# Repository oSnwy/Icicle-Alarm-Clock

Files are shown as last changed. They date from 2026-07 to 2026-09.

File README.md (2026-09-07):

# Icicle-Alarm-Clock

## Finished Build Images

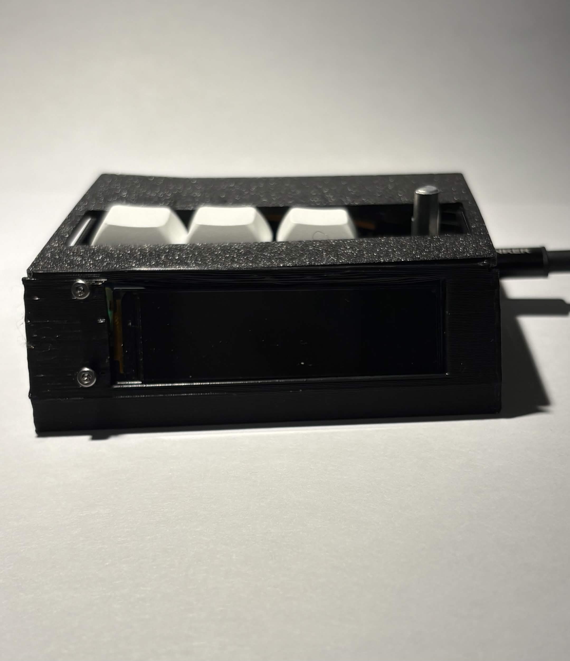
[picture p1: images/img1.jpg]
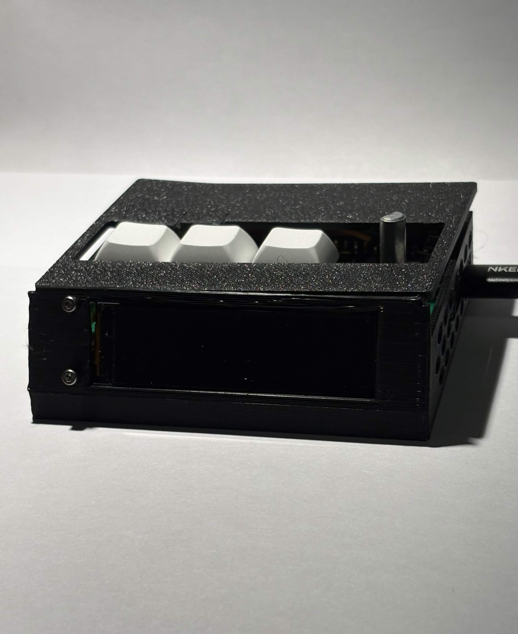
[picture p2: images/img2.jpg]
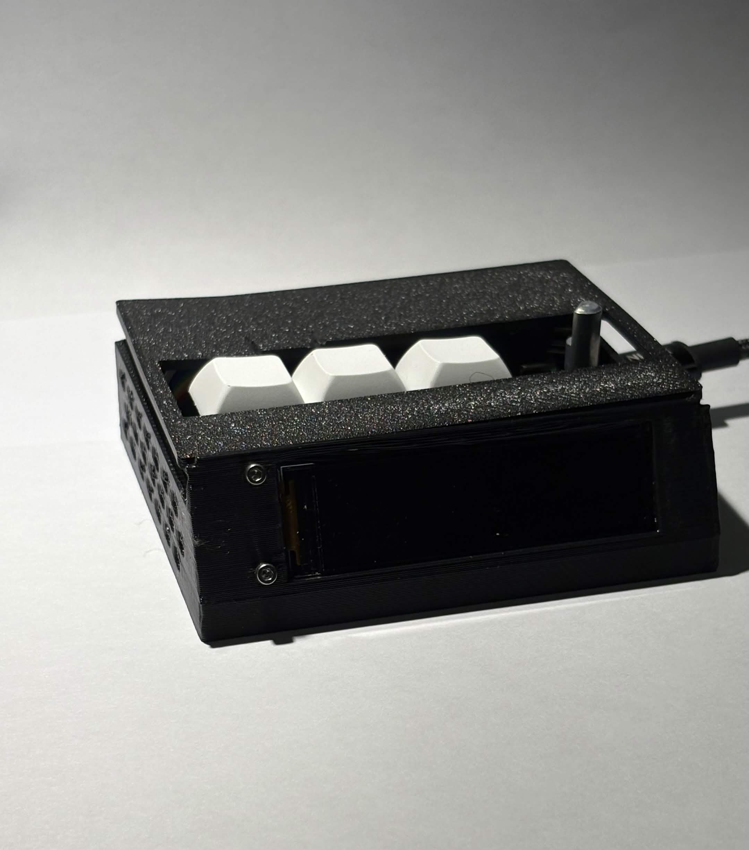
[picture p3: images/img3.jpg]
| </p> | </p> |  </p> |
| - | - | - |

<p align="center">
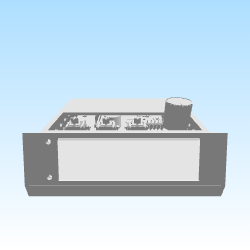
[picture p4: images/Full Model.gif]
  </p>
</p>

## Initial goals:
### Priority Goals:
- This alarm clock should be able to tell the time (obviously).
- This alarm clock should be able to store multiple alarms, as well as be able to toggle each alarm.
### Less important goals
- This alarm clock should have a volume knob.
- This alarm clock should be able to play customized sounds.

## Parts list (Bill of Materials)

| Part | Quantity | Price | Link |  
| --- | --- | --- | --- |
| Lolin C3 Mini ESP32 | 1 | Provided in Kit | N/A |
| 2.25in TFT display | 1 | Provided in Kit | N/A |
| Custom PCB | 1 | $8.67 | JLPCB |
| 3.3V Piezo Buzzer | 1 | Provided in Kit | N/A |
| EC11 Rotary Encoder Switch Button | 1 | $7.55 CAD | [AliExpress](https://www.aliexpress.com/item/1005008610645902.html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) |
| 1k ohm Resistor | 1 | $0.88 CAD | [AliExpress](https://www.aliexpress.com/item/1005007643210127.html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) |
| 10k Ohm Resistor | 1 | $0.88 CAD | [AliExpress](https://www.aliexpress.com/item/1005007643210127.html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) |
| S8050 Transistor | 1 | $7.47 CAD | [AliExpress](https://www.aliexpress.com/item/1005006811049225.html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) |
| Case | 1 | Provided in Kit | N/A |
| Lid | 1 | Provided in Kit | N/A |
| 1x8 2.54mm pin headers | 2 | $3.72 CAD | [AliExpress](https://www.aliexpress.com/item/32847429443.html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) |
| Keyboard Switches | 3 | Provided in Kit | N/A |
| Keyboard Keycaps | 3 | Provided in Kit | N/A |
| Male to male Dupont wires | 16 | $3.50 CAD | [AliExpress](https://www.aliexpress.com/item/4000109443054.html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) | 

| Price | HST (Ontario Sales Tax) | Total Price | Total USD Price |  
| --- | --- | --- | --- |
| $32.67 CAD |  $4.25 CAD HST) | $36.92 CAD | 26.01 USD |

## Planning:
- I plan to use a rotary encoder with a switch to navigate the UI, as well as extra switches to toggle alarms or other features easily.
- The buzzer will be integrated into a transistor circuit, increasing the volume of the alarm while keeping it adjustable.

## Schemtaic (4 Hours):
- Due to the struggle for GPIO pins on the WEMOS, I was only able to add two switches.
- The rotary encoder and two switches use 5 GPIO pins, while the buzzer uses one.
- The THT display uses the other 6 GPIO pins.
- The 3.3V pin powers both the buzzer and the THT display.
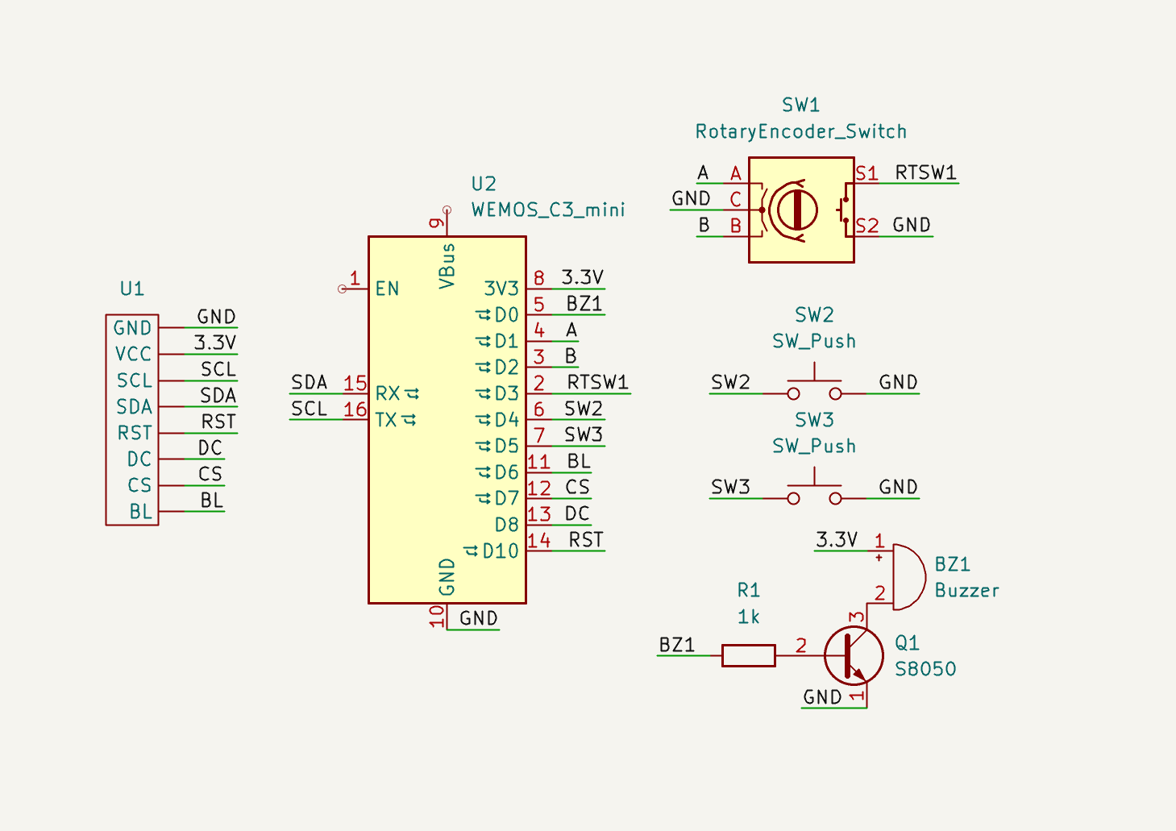
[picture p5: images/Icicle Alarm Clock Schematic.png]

  
## Schematic (REVISED: +2 Hours):
- While creating the PCB, I added a pull-down resistor between the base of the transistor circuit and the GND pin.
- I changed the THT display to be connected with a generic 2.54mm 1x8 connector, so the keys and screen can be mounted on separate planes.
- The BL is now powered by the 3.3V pin, freeing the GPIO pin to be used for a third switch.
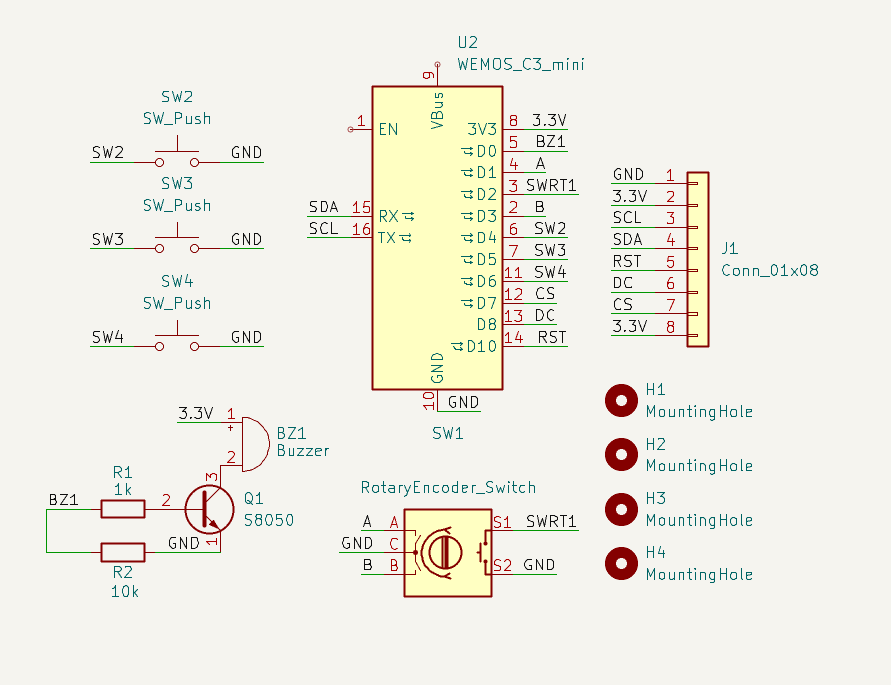
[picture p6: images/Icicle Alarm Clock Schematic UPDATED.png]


## PCB (4 Hours)
- The PCB was wired in KiCad, using the footprints provided by Hack Club [BLARE](https://github.com/destroyer796/BLARE-Alarm-Clock/tree/main).
- All components were mounted on the top of the PCB.
- The PCB includes 4 mounting holes for M3 screws.
- This PCB uses a 1x8 connector for the display.
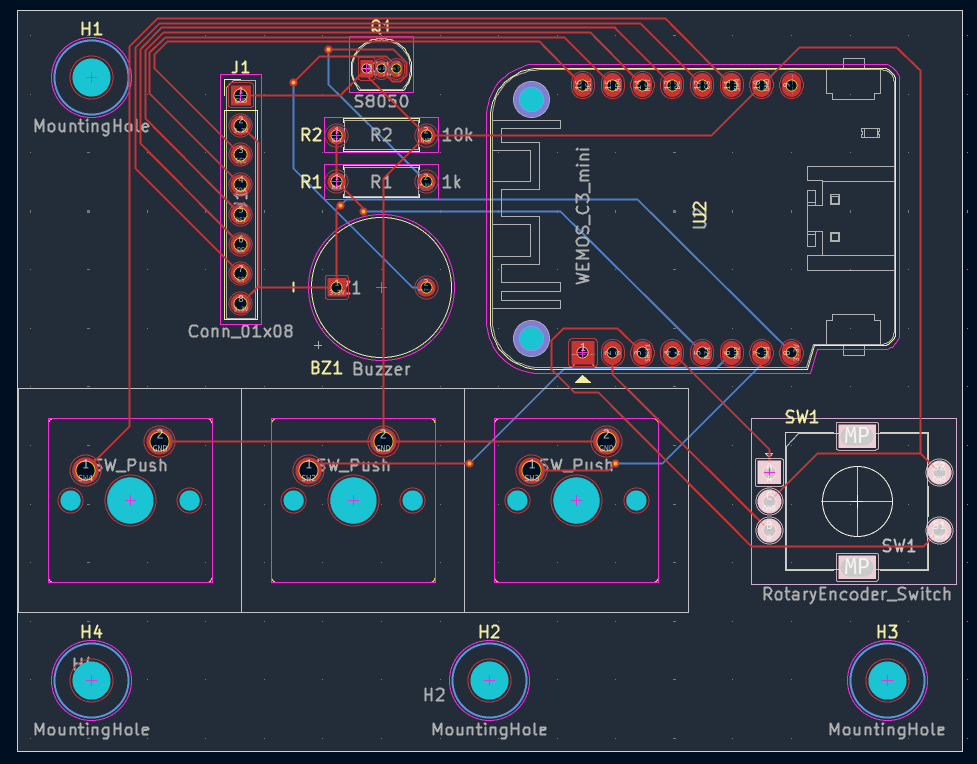
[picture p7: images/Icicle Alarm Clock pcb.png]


## Case (3 Hours)
This case is designed to work in two parts. The main body of the case has M3 screw standoffs in the base, allowing the PCB to be screwed into the case securely. The LCD can be attached to the front of the case using M2 screws in the hole in the front. The lid functions as a quick access to all the componenets inside, as well as contains a hole to reach the knob and switches. The side of the case contains cutouts to better transmit the sound of the buzzer.
- All 3d files can be found in the 3d model folder.
- The case and lid are stored in [/3d models/STEP files/Alarm Clock Base.step](https://github.com/oSnwy/Icicle-Alarm-Clock/blob/main/3d%20models/STEP%20files/Alarm%20Clock%20Base.step) and [/3d models/STEP files/Alarm Clock Lid.step](https://github.com/oSnwy/Icicle-Alarm-Clock/blob/main/3d%20models/STEP%20files/Alarm%20Clock%20Lid.step)

## CASE (REVISED: +2 Hours):
Added holes for the usb c wire, as well as a lower lid for easier access to the switches. Also added full electronics 3d model.

### Full Model With Electronics

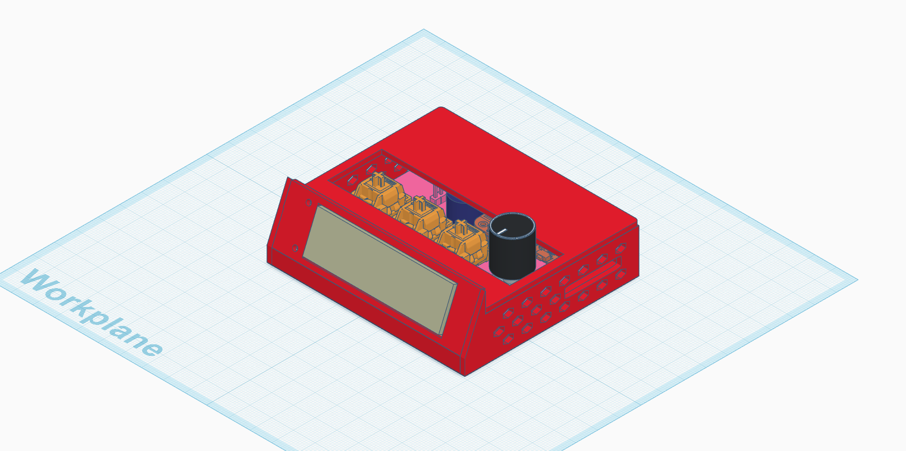
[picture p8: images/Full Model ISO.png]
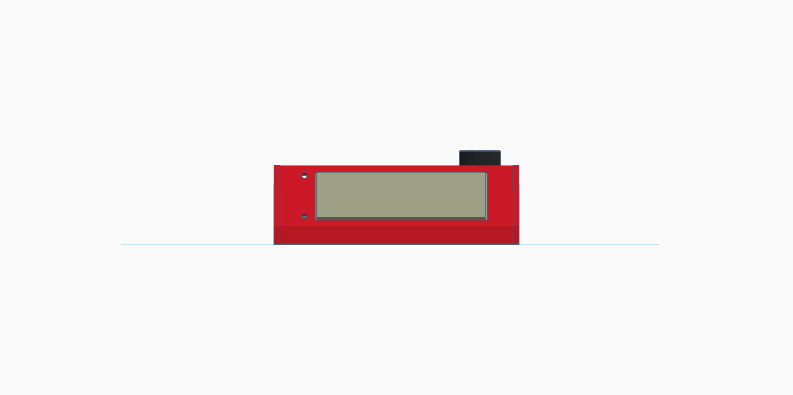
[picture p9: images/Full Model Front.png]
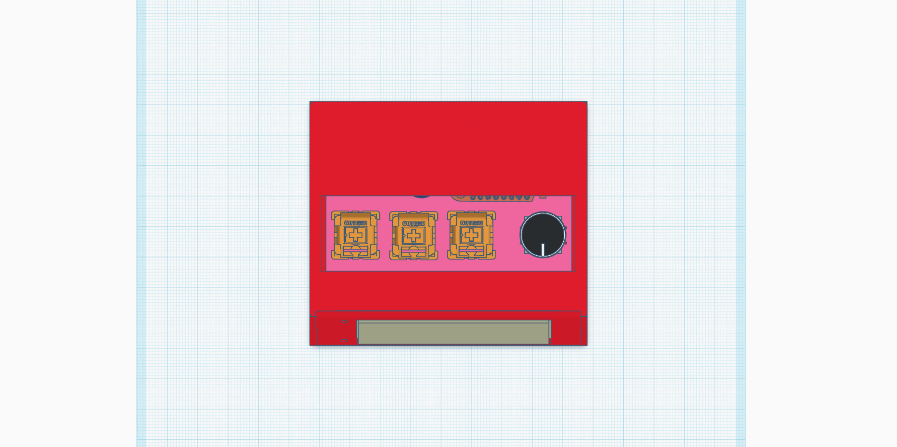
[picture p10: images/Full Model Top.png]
|  |  |  |
|-|-|-|
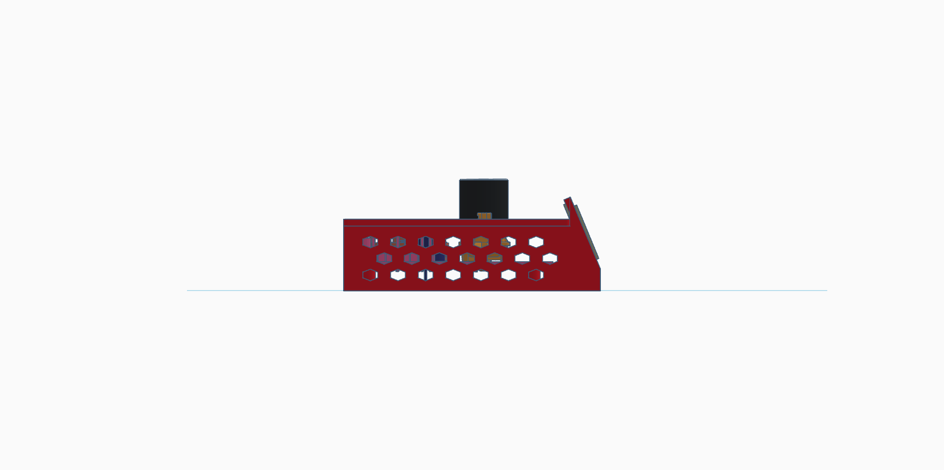
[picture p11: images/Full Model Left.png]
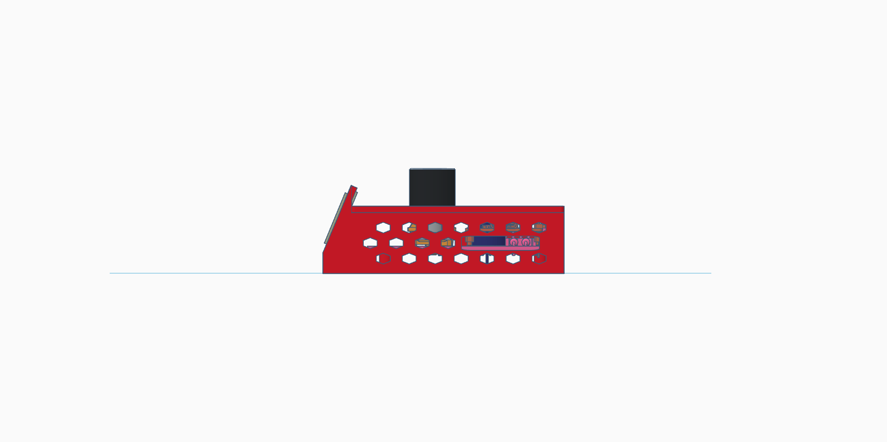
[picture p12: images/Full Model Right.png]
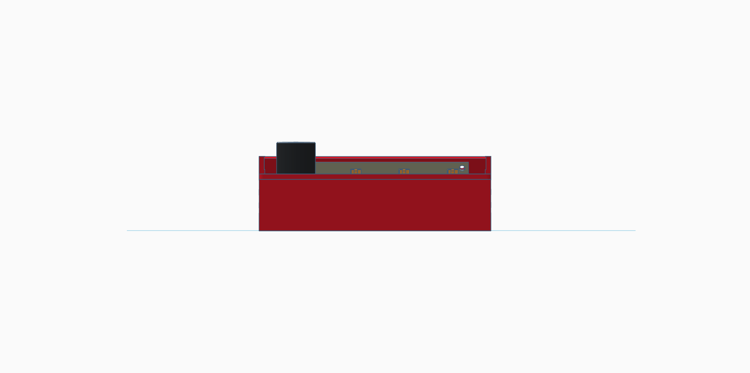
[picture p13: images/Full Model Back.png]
|  |  |  |

### Case

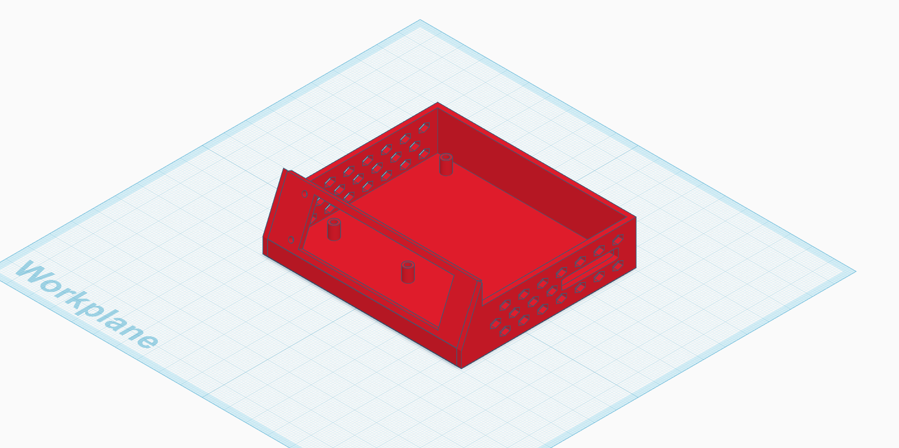
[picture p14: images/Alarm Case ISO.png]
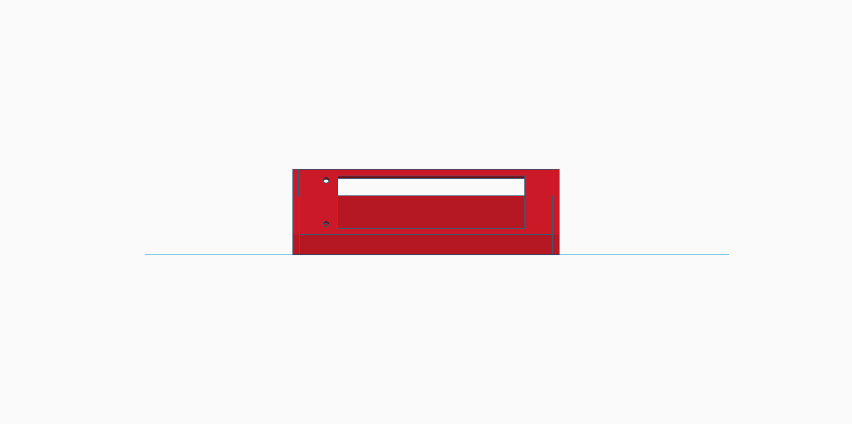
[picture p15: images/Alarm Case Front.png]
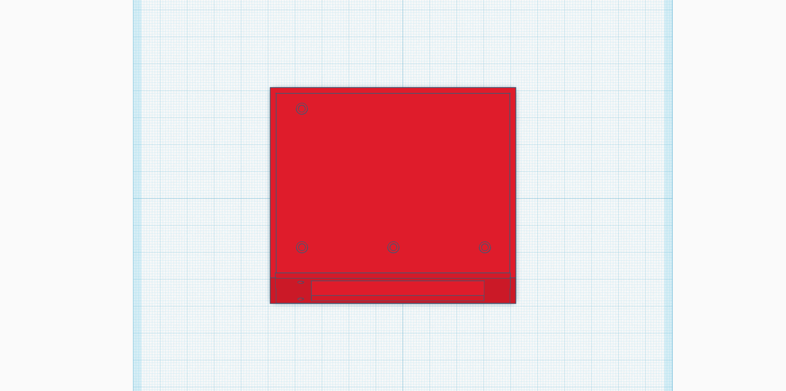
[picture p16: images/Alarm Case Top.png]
|  |  |  |
|-|-|-|
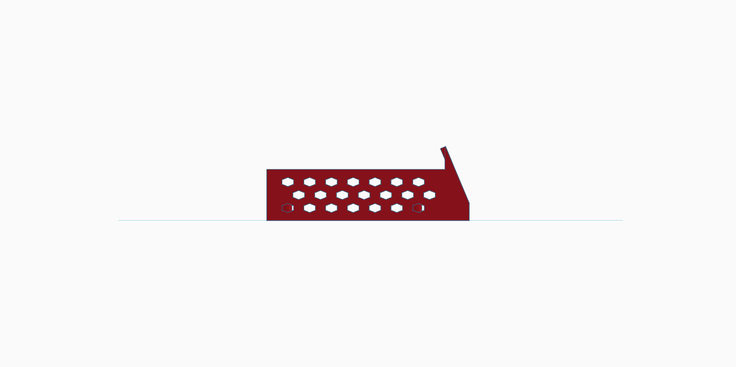
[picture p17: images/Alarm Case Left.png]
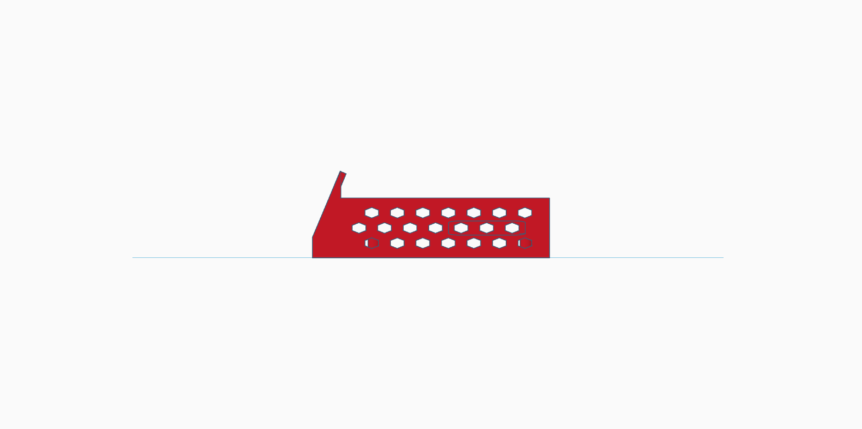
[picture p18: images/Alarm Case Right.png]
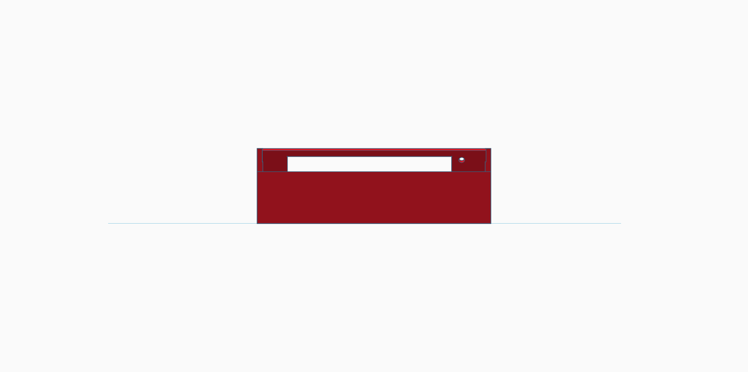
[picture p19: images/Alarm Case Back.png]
|  |  |  |

### Lid

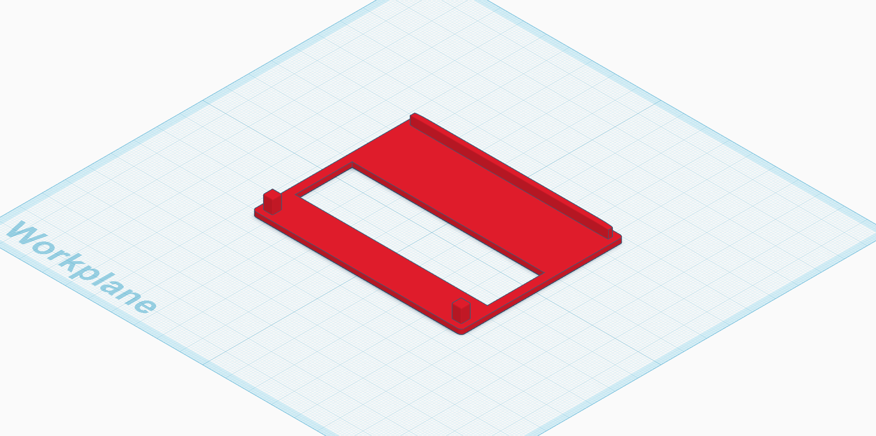
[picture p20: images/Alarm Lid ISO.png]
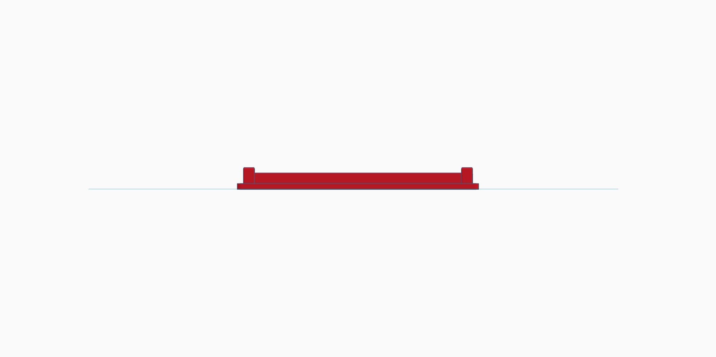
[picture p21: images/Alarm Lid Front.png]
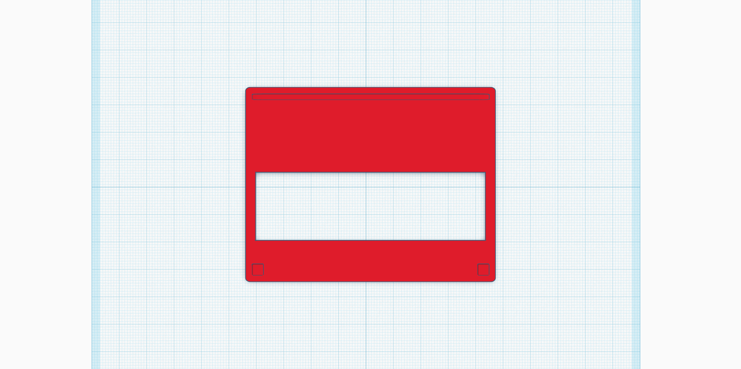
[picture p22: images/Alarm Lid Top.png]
|  |  |  |
|-|-|-|
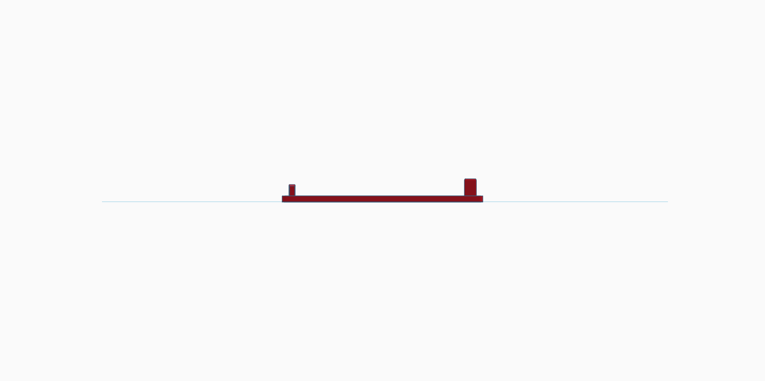
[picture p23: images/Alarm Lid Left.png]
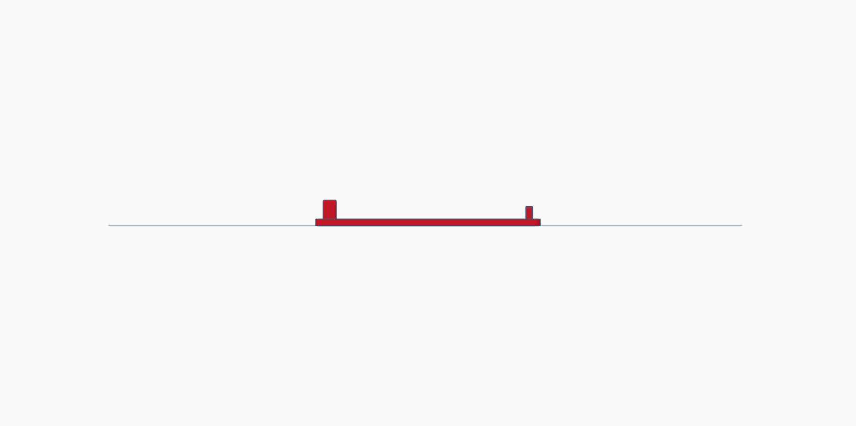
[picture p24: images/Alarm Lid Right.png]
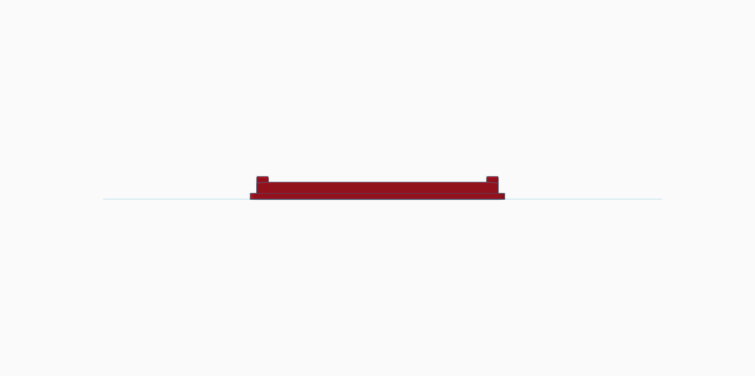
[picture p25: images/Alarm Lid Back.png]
|  |  |  |

## Code (8 Hours)
Easily the longest part of the project. The code was written in C++ in the Arduino IDE. I used the wifi capabilities of the ESP32 to sync the time accurately without an RTC. This allows me to retrieve the time from pool.ntp.org, but does mean that it must be connected to the wifi. However, we can use the rotary encoder and the switches in order to mantually adjust the time if needed, such as when wifi is not possible.

### Resources Used
If anyone wants to learn how to code an Alarm Clock, these are some excellent resources to get started with.

| Use | Website |
| - | - |
| Install ESP32 in Arduino IDE | https://randomnerdtutorials.com/installing-the-esp32-board-in-arduino-ide-windows-instructions/ |
| How to connect ESP32 to wifi | https://randomnerdtutorials.com/getting-started-esp32-c3-super-mini/ |
| How to get the time on an ESP32 | https://randomnerdtutorials.com/esp32-date-time-ntp-client-server-arduino/ |
| struct TM reference sheet | https://cplusplus.com/reference/ctime/tm/ |
| WEMOS C3 mini reference sheet | https://www.wemos.cc/en/latest/c3/c3_mini.html |

Keep in mind that the type of microcontroller you are using may affect the firmware.

### Libraries
```C++
#include <Adafruit_GFX.h>
#include <Adafruit_ST7789.h>
#include <SPI.h>
#include <WiFi.h>
#include "time.h"
```
I used Adafruit and SPI to connect the microcontroller to the THT display, and wifi.h and time.h to get and store the time from pool.ntp.org. You may need to download the libraries before using them.

### Pins
```C++
#define BZ1 0
#define ENC_A 1
#define ENC_SW1 2
#define ENC_B 3
#define SW2 4
#define SW3 5
#define SW4 6
#define TFT_CS 7
#define TFT_DC 8
#define TFT_RST 10
#define TFT_MOSI 20
#define TFT_SCLK 21
```
Defining each pin of the microcontroller makes it easier and more organized. This will change depending on how your microcontroller is wired.

### Setting up Wifi and Time
```C++
const char* ssid = "wifi name";
const char* password = "wifi password";
const char* ntpServer = "pool.ntp.org";

const long gmtOffset_sec = -18000; // offset from gmt to test (-5 hours)
const int daylightOffset_sec = 3600; //off set froim daylight savings
```
We can access the wifi by using the ssid and password, which allows us to connect to the network later. The time can be found by getting the GMT timezone and offsetting it by the difference from GMT to EST, which is -5 hours. We can also use daylight savings offset to fix the hour difference.

### Display
```C++
Adafruit_ST7789 tft = Adafruit_ST7789(TFT_CS, TFT_DC, TFT_MOSI, TFT_SCLK, TFT_RST);
void setup() {
  Serial.begin(115200);a
  tft.init(284, 76);             
  tft.setColRowStart(82, 18);    
  tft.setRotation(2);            
  Serial.println("TFT Initialized!");

  tft.fillScreen(ST77XX_BLACK);  
  tft.setCursor(0, 0);           
  tft.setTextSize(2);          
  tft.print("Intializing");
}
```
This simply sets up the screen.

### Clock
```C++
int tries = 0;
  WiFi.begin(ssid, password);
  while (WiFi.status() != WL_CONNECTED && tries < 30) {
    delay(500);
    Serial.print(".");
    tries++;
  }
  
  configTime(gmtOffset_sec, daylightOffset_sec, ntpServer);

  if (getLocalTime(&timeinfo)) {
      Serial.println("Time synced!");
      showMessage("Time synced!");
      delay(1000);
    } else {
      Serial.println("Time sync failed!");
      showMessage("Time sync failed");
      delay(1500);
    }
  } else {
    Serial.println("\nWiFi failed!");
    showMessage("WiFi failed");
    delay(1500);
```
This block of code allows us to sync the internal clock of the microcontroller to the timezone, as well as any offsets.

### Alarm
```C++
void checkAlarm() { // check if its time to get up
  int hour, minute, second;

  if (!getCurrentTime(hour, minute, second)) {
    return;
  }

  // Reset the one-minute trigger lock when we leave the alarm minute.
  if (minute != alarmMinute) {
    alarmTriggeredThisMinute = false;
  }

  // If alarm is enabled and time matches, start ringing.
  if (
    alarmEnabled &&
    !alarmRinging &&
    !alarmTriggeredThisMinute &&
    hour == alarmHour &&
    minute == alarmMinute
  ) {
    alarmRinging = true;
    alarmTriggeredThisMinute = true;
  }
}

void updateBuzzer() { // if its time to get up gotta get the buzzer going
  if (!alarmRinging) {
    noTone(BZ1);
    beepOn = false;
    return;
  }

  // Make the alarm beep on/off every 300 ms.
  if (millis() - lastBeepToggle > 300) {
    lastBeepToggle = millis();
    beepOn = !beepOn;

    if (beepOn) {
      tone(BZ1, 2000);   // 2000 Hz beep
    } else {
      noTone(BZ1);
    }
  }
}
```
We can use a function in order to check whether the alarm should be going off. The updateBuzzer function allows us to make the buzzer beep on and off, as well as test when it should be stopped.

### Clock Adjustment
```C++
void changeValue(int amount) { 
  if (mode == SET_ALARM_MINUTE) {
      alarmMinute += amount;
  if (mode == SET_ALARM_HOUR) {
      alarmHour += amount;
}
```
We can use the rotary knob and switches in tandem to adjust the clock's time in case of desync.
```C++
// SW2 can set hour time
  if (buttonPressed(sw2State, lastSW2)) {
    mode = SET_ALARM_HOUR;
    lastButtonTime = millis();
  }

  // SW3 toggles alarm on/off
  if (buttonPressed(sw3State, lastSW3)) {
    alarmEnabled = !alarmEnabled;
    mode = SHOW_TIME;
    lastButtonTime = millis();
  }

  // SW4 goes back to main screen
  if (buttonPressed(sw4State, lastSW4)) {
    mode = SHOW_TIME;
    lastButtonTime = millis();
  }

  // Rotary encoder switch moves between setting hour and minute
  if (buttonPressed(encSWState, lastEncSW)) {
    if (mode == SHOW_TIME) {
      mode = SET_ALARM_HOUR;
    } else if (mode == SET_ALARM_HOUR) {
      mode = SET_ALARM_MINUTE;
    } else if (mode == SET_ALARM_MINUTE) {
      mode = SHOW_TIME;
    }
```
The detection of the switches and rotary encoder allows us to change the UI and set the alarm and clock.

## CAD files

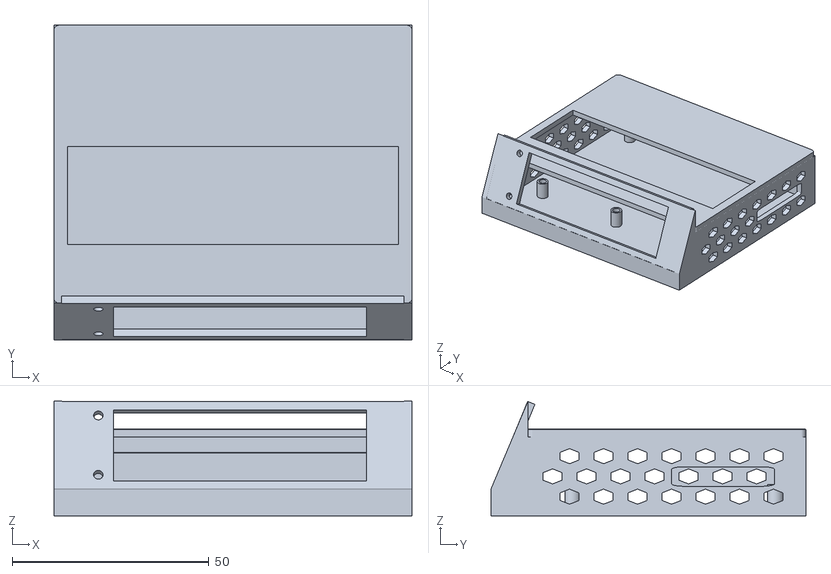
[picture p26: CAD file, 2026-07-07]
3d models/STL files/Full Model wo Electronics.stl
90.9 x 80.0 x 29.1

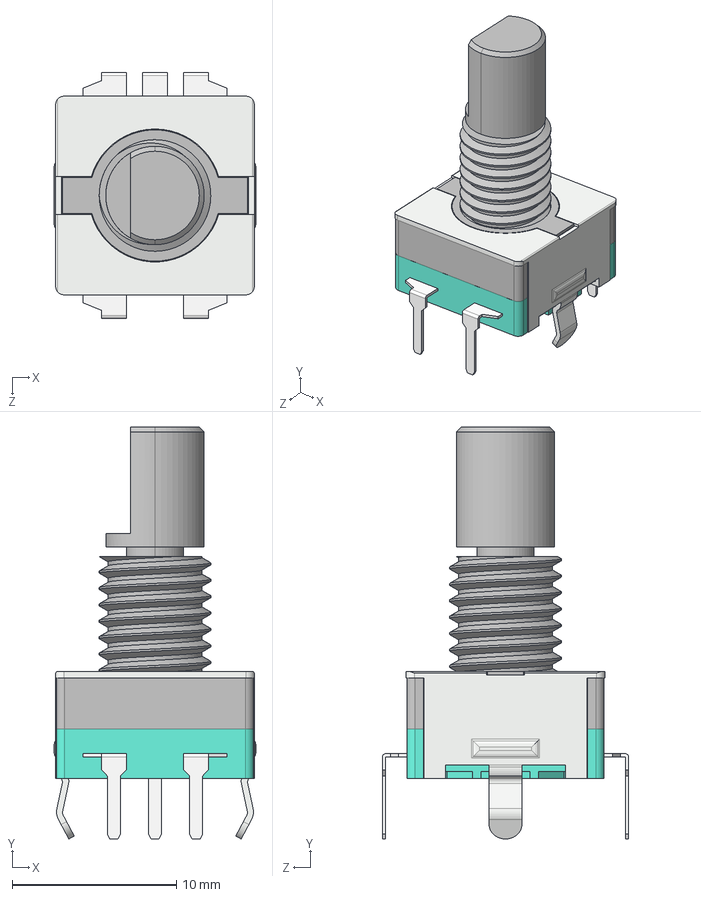
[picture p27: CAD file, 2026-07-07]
3d models/Parts/rotary encoder.STEP
12.3 x 25.1 x 15.0 mm

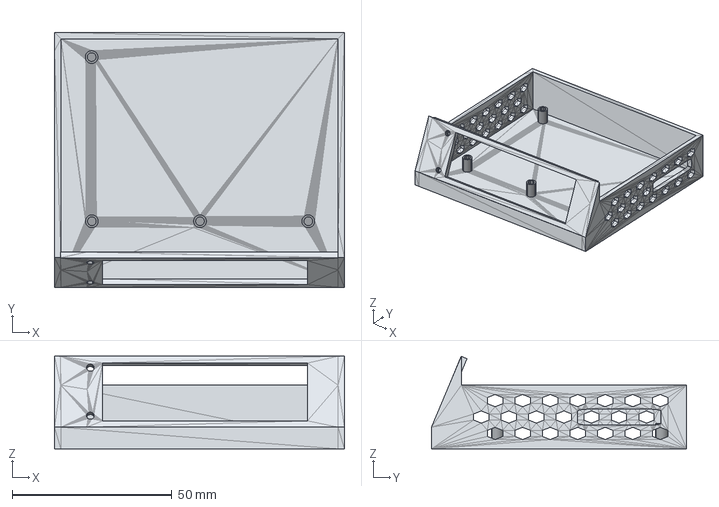
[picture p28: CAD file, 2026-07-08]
3d models/STEP files/Alarm Clock Base v2.step
90.9 x 80.0 x 29.1 mm

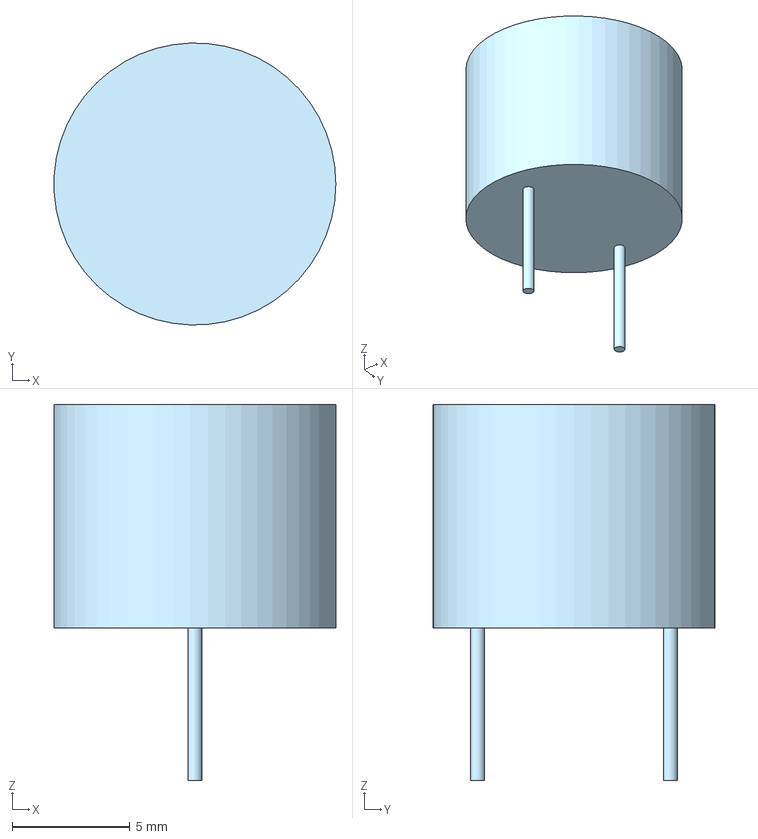
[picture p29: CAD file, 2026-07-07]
3d models/Parts/Buzzer.step
12.0 x 12.0 x 16.0 mm

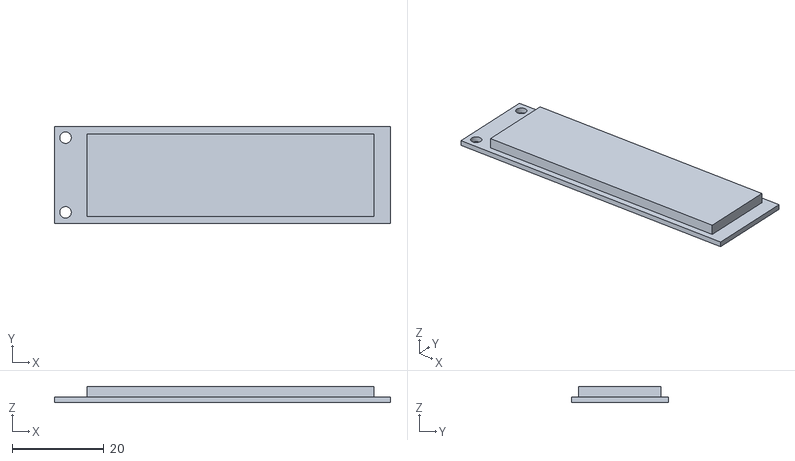
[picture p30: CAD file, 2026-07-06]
3d models/STL files/2.25in TFT Display(1).stl
73.2 x 21.1 x 3.56

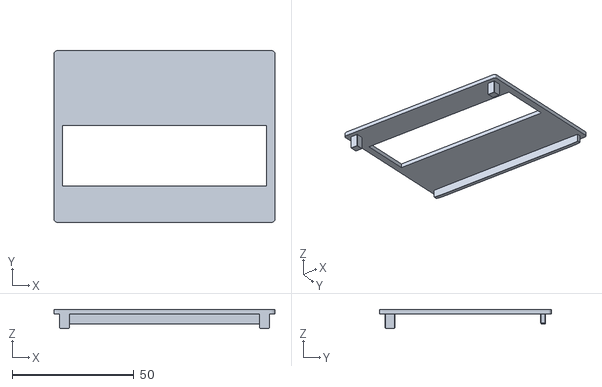
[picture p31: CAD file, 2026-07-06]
3d models/STL files/Alarm Clock Lid.stl
90.9 x 70.7 x 8.00

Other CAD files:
3d models/Parts/2.25in TFT Display.step
3d models/STL files/Alarm Clock Base.stl
3d models/STL files/Buzzer.stl

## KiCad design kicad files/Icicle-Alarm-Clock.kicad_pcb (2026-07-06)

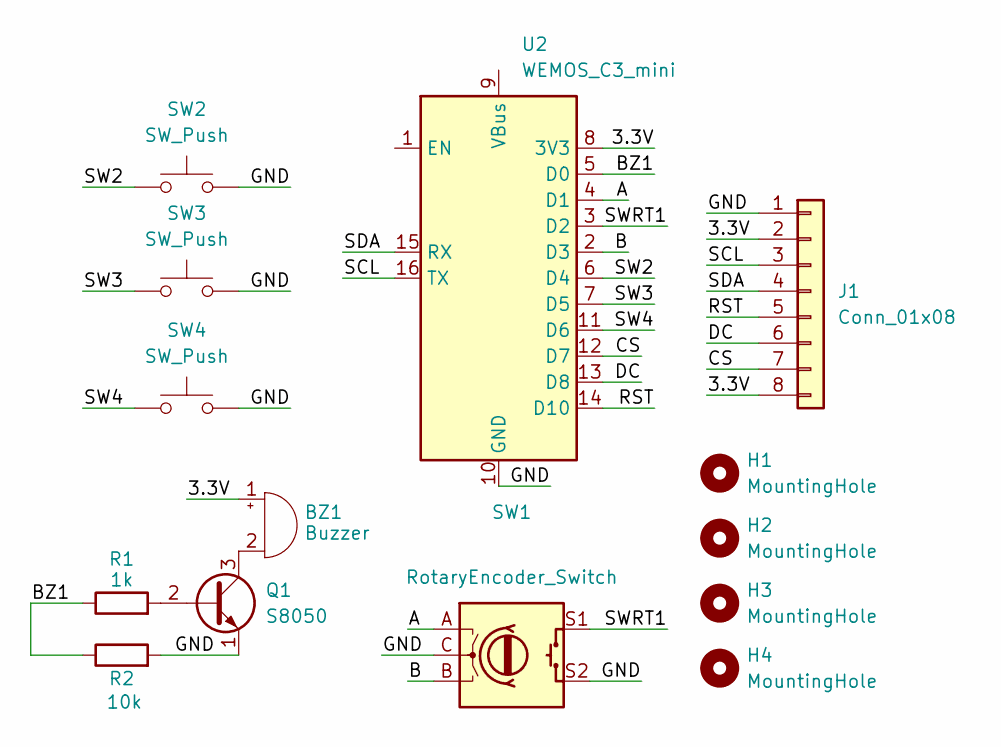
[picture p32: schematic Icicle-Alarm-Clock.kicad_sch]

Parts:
BZ1: Buzzer; Buzzer_12x9.5RM7.6
H1, H2, H3, H4: MountingHole; MountingHole_3.2mm_M3
J1: Conn_01x08; PinHeader_1x08_P2.54mm_Vertical
Q1: S8050; TO-92_Inline
R1: 1k; R_Axial_DIN0207_L6.3mm_D2.5mm_P7.62mm_Horizontal
R2: 10k; R_Axial_DIN0207_L6.3mm_D2.5mm_P7.62mm_Horizontal
SW1: RotaryEncoder_Switch; RotaryEncoder_Alps_EC11E-Switch_Vertical_H20mm
SW2, SW3, SW4: SW_Push; SW_MX_1u
U2: WEMOS_C3_mini

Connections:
/3.3V: BZ1.1 (+), J1.2, J1.8, U2.8 (3V3)
/A: SW1.A, U2.4 (D1)
/B: SW1.B, U2.2 (D3)
/BZ1: R1.1, R2.1, U2.5 (D0)
/CS: J1.7, U2.12 (D7)
/DC: J1.6, U2.13 (D8)
/GND: J1.1, Q1.1 (E), R2.2, SW1.C, SW1.S2, SW2.2, SW3.2, SW4.2, U2.10 (GND)
/RST: J1.5, U2.14 (D10)
/SCL: J1.3, U2.16 (TX)
/SDA: J1.4, U2.15 (RX)
/SW2: SW2.1, U2.6 (D4)
/SW3: SW3.1, U2.7 (D5)
/SW4: SW4.1, U2.11 (D6)
/SWRT1: SW1.S1, U2.3 (D2)
unnamed: BZ1.2 (-), Q1.3 (C)
unnamed: Q1.2 (B), R1.2

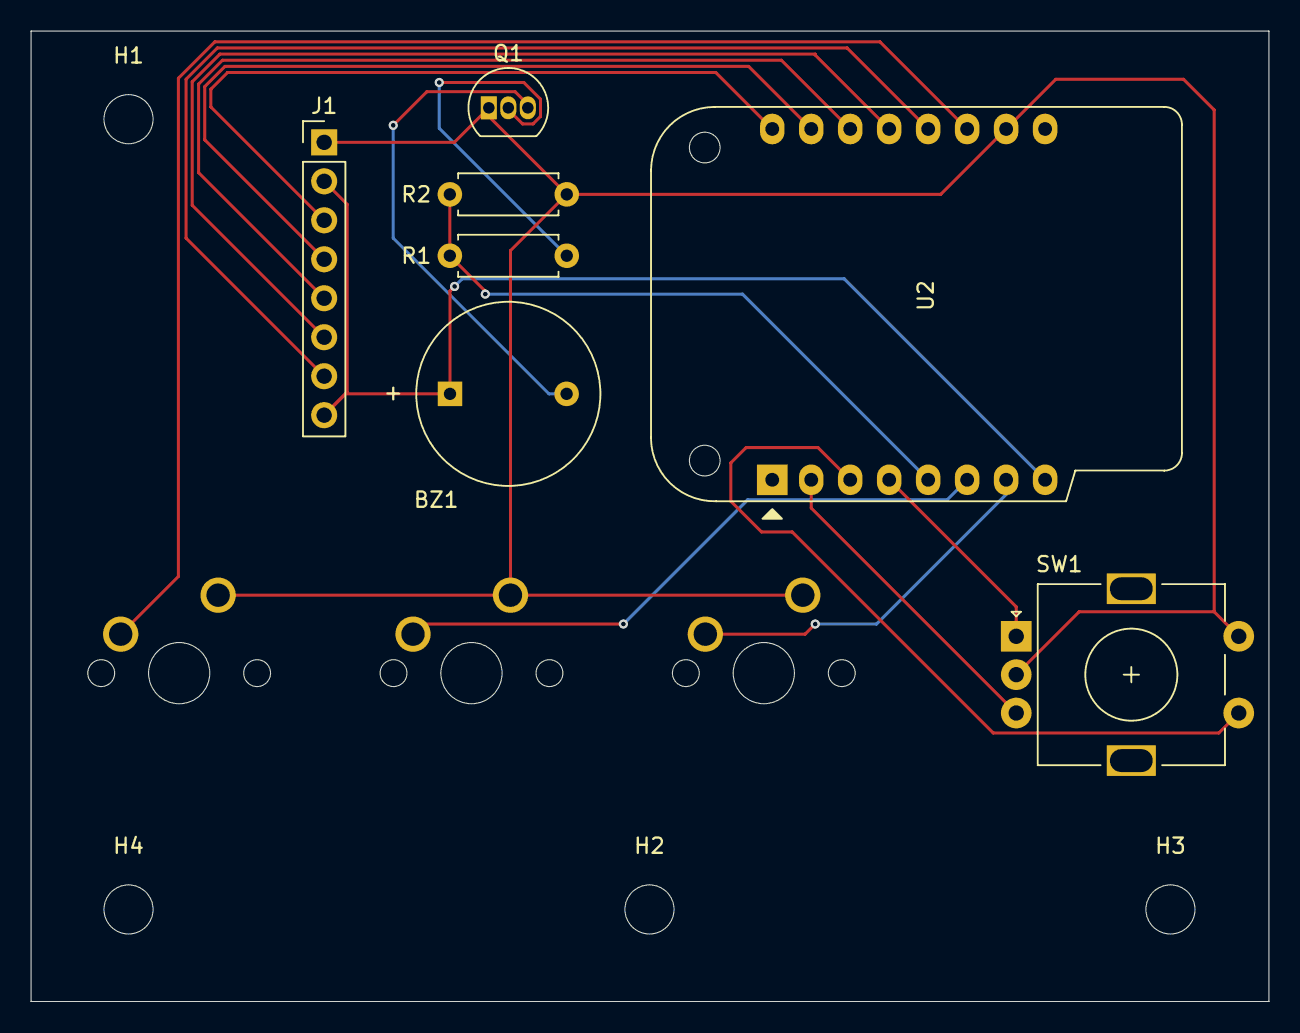
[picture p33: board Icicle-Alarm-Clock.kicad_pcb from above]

Board: 2 copper layers, 80.7 x 63.2 mm, 14 parts (0 on the bottom side), 16 nets.

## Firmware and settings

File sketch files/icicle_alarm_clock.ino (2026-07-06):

#include <Adafruit_GFX.h>
#include <Adafruit_ST7789.h>
#include <SPI.h>
#include <WiFi.h>
#include "time.h"

// define pins
#define BZ1 0
#define ENC_A 1
#define ENC_SW1 2
#define ENC_B 3
#define SW2 4
#define SW3 5
#define SW4 6
#define TFT_CS 7
#define TFT_DC 8
#define TFT_RST 10
#define TFT_MOSI 20
#define TFT_SCLK 21

// initialize screen object
Adafruit_ST7789 tft = Adafruit_ST7789(TFT_CS, TFT_DC, TFT_MOSI, TFT_SCLK, TFT_RST);

//set wifi for better time accuracy
const char* ssid = "wifi name";
const char* password = "wifi password";
const char* ntpServer = "pool.ntp.org";

const long gmtOffset_sec = -18000; // offset from gmt to test (-5 hours)
const int daylightOffset_sec = 3600; //off set froim daylight savings

void setup() {
  Serial.begin(115200);a
  tft.init(284, 76);             // screen dimensions
  tft.setColRowStart(82, 18);    // offsets to line up this unusual panel
  tft.setRotation(2);            // orientation, could be different, try 0-3
  Serial.println("TFT Initialized!");

  tft.fillScreen(ST77XX_BLACK);  // clear the screen
  tft.setCursor(0, 0);           // top-left corner
  tft.setTextSize(2);            // a readable size
  tft.print("Intializing");

 //connect to wifi
  int tries = 0;
  WiFi.begin(ssid, password);
  while (WiFi.status() != WL_CONNECTED && tries < 30) {
    delay(500);
    Serial.print(".");
    tries++;
  }
  
  configTime(gmtOffset_sec, daylightOffset_sec, ntpServer);

  if (getLocalTime(&timeinfo)) {
      Serial.println("Time synced!");
      showMessage("Time synced!");
      delay(1000);
    } else {
      Serial.println("Time sync failed!");
      showMessage("Time sync failed");
      delay(1500);
    }
  } else {
    Serial.println("\nWiFi failed!");
    showMessage("WiFi failed");
    delay(1500);

  //setup rotary encoder and switches
  pinMode(BZ1, OUTPUT);
  digitalWrite(BZ1, LOW);

  pinMode(ENC_A, INPUT_PULLUP);
  pinMode(ENC_B, INPUT_PULLUP);
  pinMode(ENC_SW1, INPUT_PULLUP);

  pinMode(SW2, INPUT_PULLUP);
  pinMode(SW3, INPUT_PULLUP);
  pinMode(SW4, INPUT_PULLUP);  
}



void loop() {
   readEncoder();
  readButtons();
  checkAlarm();
  updateBuzzer();

  // Redraw the screen every 250 milliseconds
  if (millis() - lastDisplayUpdate > 250) {
    printTime();
    lastDisplayUpdate = millis();
}

void printTime (){
  int hour, minute, second;

  bool timeValid = getCurrentTime(hour, minute, second);

  tft.fillScreen(ST77XX_BLACK);
  tft.setCursor(0, 0);

  if (alarmRinging) {
    tft.setTextColor(ST77XX_RED);
    tft.setTextSize(3);
    tft.println("ALARM!");

    tft.setTextColor(ST77XX_WHITE);
    tft.setTextSize(1);
    tft.println("Press any button");
    return;
  }

  tft.setTextColor(ST77XX_WHITE);
  tft.setTextSize(2);

  if (timeValid) {
    tft.print("Time ");
    printTwoDigits(hour);
    tft.print(":");
    printTwoDigits(minute);
    tft.print(":");
    printTwoDigits(second);
  } else {
    tft.print("No time sync");
  }

  tft.setCursor(0, 25);
  tft.print("Alarm ");
  printTwoDigits(alarmHour);
  tft.print(":");
  printTwoDigits(alarmMinute);

  tft.print(" ");

  if (alarmEnabled) {
    tft.print("ON");
  } else {
    tft.print("OFF");
  }

  tft.setCursor(0, 50);
  tft.setTextSize(1);
  tft.setTextColor(ST77XX_YELLOW);

  if (mode == SHOW_TIME) {
    tft.print("SW2 set  SW3 on/off");
  } else if (mode == SET_ALARM_HOUR) {
    tft.print("Set alarm HOUR");
  } else if (mode == SET_ALARM_MINUTE) {
    tft.print("Set alarm MINUTE");
  }

}

void checkAlarm() { // check if its time to get up
  int hour, minute, second;

  if (!getCurrentTime(hour, minute, second)) {
    return;
  }

  // Reset the one-minute trigger lock when we leave the alarm minute.
  if (minute != alarmMinute) {
    alarmTriggeredThisMinute = false;
  }

  // If alarm is enabled and time matches, start ringing.
  if (
    alarmEnabled &&
    !alarmRinging &&
    !alarmTriggeredThisMinute &&
    hour == alarmHour &&
    minute == alarmMinute
  ) {
    alarmRinging = true;
    alarmTriggeredThisMinute = true;
  }
}

void updateBuzzer() { // if its time to get up gotta get the buzzer going
  if (!alarmRinging) {
    noTone(BZ1);
    beepOn = false;
    return;
  }

  // Make the alarm beep on/off every 300 ms.
  if (millis() - lastBeepToggle > 300) {
    lastBeepToggle = millis();
    beepOn = !beepOn;

    if (beepOn) {
      tone(BZ1, 2000);   // 2000 Hz beep
    } else {
      noTone(BZ1);
    }
  }
}

void readEncoder() { // read the encoder
  int encA = digitalRead(ENC_A);

  // Detect one step of rotation.
  if (encA != lastEncA && encA == LOW) {
    int encB = digitalRead(ENC_B);

    if (encB == HIGH) {
      changeValue(1);
    } else {
      changeValue(-1);
    }
  }

  lastEncA = encA;
}

void changeValue(int amount) { // allows user to set the time in case its a little off
  if (alarmRinging) {
    return;
  }

  if (mode == SET_ALARM_HOUR) {
    alarmHour += amount;

    if (alarmHour < 0) {
      alarmHour = 23;
    }

    if (alarmHour > 23) {
      alarmHour = 0;
    }
  }

  if (mode == SET_ALARM_MINUTE) {
    alarmMinute += amount;

    if (alarmMinute < 0) {
      alarmMinute = 59;
    }

    if (alarmMinute > 59) {
      alarmMinute = 0;
    }
  }
}

void readButtons() { // reads the buttons on the pcb
  bool sw2State = digitalRead(SW2);
  bool sw3State = digitalRead(SW3);
  bool sw4State = digitalRead(SW4);
  bool encSWState = digitalRead(ENC_SW1);

  // debounce so one press does not count many times
  if (millis() - lastButtonTime < debounceDelay) {
    lastSW2 = sw2State;
    lastSW3 = sw3State;
    lastSW4 = sw4State;
    lastEncSW = encSWState;
    return;
  }

  // If alarm is ringing, any button stops it
  if (alarmRinging) {
    if (
      buttonPressed(sw2State, lastSW2) ||
      buttonPressed(sw3State, lastSW3) ||
      buttonPressed(sw4State, lastSW4) ||
      buttonPressed(encSWState, lastEncSW)
    ) {
      stopAlarm();
      lastButtonTime = millis();
    }

    lastSW2 = sw2State;
    lastSW3 = sw3State;
    lastSW4 = sw4State;
    lastEncSW = encSWState;
    return;
  }

  // SW2 can set hour time
  if (buttonPressed(sw2State, lastSW2)) {
    mode = SET_ALARM_HOUR;
    lastButtonTime = millis();
  }

  // SW3 toggles alarm on/off
  if (buttonPressed(sw3State, lastSW3)) {
    alarmEnabled = !alarmEnabled;
    mode = SHOW_TIME;
    lastButtonTime = millis();
  }

  // SW4 goes back to main screen
  if (buttonPressed(sw4State, lastSW4)) {
    mode = SHOW_TIME;
    lastButtonTime = millis();
  }

  // Rotary encoder switch moves between setting hour and minute
  if (buttonPressed(encSWState, lastEncSW)) {
    if (mode == SHOW_TIME) {
      mode = SET_ALARM_HOUR;
    } else if (mode == SET_ALARM_HOUR) {
      mode = SET_ALARM_MINUTE;
    } else if (mode == SET_ALARM_MINUTE) {
      mode = SHOW_TIME;
    }

    lastButtonTime = millis();
  }

  lastSW2 = sw2State;
  lastSW3 = sw3State;
  lastSW4 = sw4State;
  lastEncSW = encSWState;
}

bool buttonPressed(bool currentState, bool previousState) {
  return previousState == HIGH && currentState == LOW;
}

void showMessage(const char* message) { // showws a messagfe for wifi and UI
  tft.fillScreen(ST77XX_BLACK);
  tft.setCursor(0, 20);
  tft.setTextColor(ST77XX_WHITE);
  tft.setTextSize(2);
  tft.print(message);
}

void printTwoDigits(int number) { // helps print out the time 
  if (number < 10) {
    tft.print("0");
  }

  tft.print(number);
}
